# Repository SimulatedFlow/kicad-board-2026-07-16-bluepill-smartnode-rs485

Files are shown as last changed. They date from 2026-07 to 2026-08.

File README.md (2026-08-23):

# 2026-07-16-bluepill-smartnode-rs485

<!-- SF-STORE-BLOCK:BEGIN -->
## 🛒 Source-available — see before you buy

This repository contains the **full design files** of a commercial hardware board. It is **source-available, not open source**: read it, evaluate it, then buy a license to use it. See **LICENSE.md (source-available, purchase required)**.

**Get it / Buy:**
- **Order on eBay** (this board, bare PCB): https://www.ebay.de/itm/398222427962
- Product page (specs, photos, price): https://simulatedflow.teufel-engineering.com/platinen/2026-07-16-bluepill-smartnode-rs485/
- eBay store — all our boards and PCB art: https://www.ebay.de/usr/simula-9
- Merch shop (dev & gaming): https://simulatedflow.myspreadshop.de
- Merch shop (Synthetica / EDM): https://synthetica.myspreadshop.de
- Direct / invoice (Simulated Flow UG): simulatedflow@gmail.com

### 📬 **Free Board Documentation & Firmware Pack**

Schematics, BOMs and example-firmware docs for our STM32 carrier boards. Get it by joining the newsletter — plus a heads-up when something new ships. Double opt-in, unsubscribe in one click, no address sharing.

👉 **[Get the free pack](https://simulatedflow.teufel-engineering.com/newsletter/hardware/?q=gh)**

_© 2026 Simulated Flow UG. All rights reserved._
<!-- SF-STORE-BLOCK:END -->

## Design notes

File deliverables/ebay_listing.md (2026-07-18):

# BluePill-SmartNode-RS485 - Leerplatine fuer STM32 Bluepill (handloetbar, THT-Bausatz-Basis)

Handlötbares Träger- und Automationsboard für die STM32 Bluepill mit RS485-Bus, 2 robusten Relais-Ausgängen und Sensor-Schnittstellen.

## Highlights
- Komplett von Hand loetbar (THT / grosse Bauteile, kein SMD-Feinpitch)
- Passt direkt auf die STM32 'Bluepill' (2x 20-Pin-Buchsenleiste, 22,86 mm Reihenabstand)
- Schraubklemmen am Platinenrand - Kabel sauber nach aussen
- 4x M3-Befestigungsbohrungen fuer gaengige Gehaeuse
- 4-lagig (durchgehende GND- + Versorgungs-Plane, stoerarm/EMV-freundlich)

**Passendes Gehaeuse:** 100x80mm Eurocard-Gehäuse / DIN-Hutschienengehäuse (z. B. CamdenBoss CNMB/4)

## Einsatzzweck
Bastler verdrahten Bluepills für Haus- und Gartensteuerung meist fliegend über instabile Jumper-Kabel mit externen Modulen. Dieses Board vereint alle Kernfunktionen (Schalten, Bus, Sensorik, Stromversorgung) auf einer rein handlötbaren, störsicheren THT-Platine in Eurocard-Größe.

## Bestueckung (ca. 28 Bauteile laut Stueckliste)
- C_BULK1: 100uF/25V (x1)
- C_BULK2: 47uF/10V (x1)
- C_BULK3: 47uF/10V (x1)
- C_DEC1: 100nF (x1)
- C_DEC2: 100nF (x1)
- C_DEC3: 100nF (x1)
- C_DEC4: 100nF (x1)
- D_REVERSE: 1N4007 (x1)
- J_DS18B20: 1-Wire (x1)
- J_I2C: I2C OLED (x1)
- J_POWER: PWR_IN 9-24V (x1)
- J_REL1: K1 COM/NO/NC (x1)
- J_REL2: K2 COM/NO/NC (x1)
- J_RS485: RS485 A/B/GND (x1)
- K1: SRD-05VDC (x1)
- K2: SRD-05VDC (x1)
- LED1: RED (x1)
- LED2: GRN (x1)
- R1: 330R (x1)
- R2: 330R (x1)
- R_PULL1: 4.7k (x1)
- R_TERM: 120R (x1)
- U1: Bluepill_L (x1)
- U2: Bluepill_R (x1)

## Lieferumfang
- 1x unbestueckte Leiterplatte (Fertigung auf Bestellung via PCBWay)
- Schaltplan als PDF + Bestueckungsliste (BOM als CSV) zum Download

**Preis:** 24 EUR (unbestueckte Leerplatine, zzgl. Versand)

Fertigung auf Bestellung - Lieferzeit nach PCBWay-Produktion. Gewerblicher Verkauf durch Simulated Flow UG: gesetzliches Widerrufsrecht und Gewaehrleistung gemaess AGB/Impressum. Versand als versicherter Warenversand.

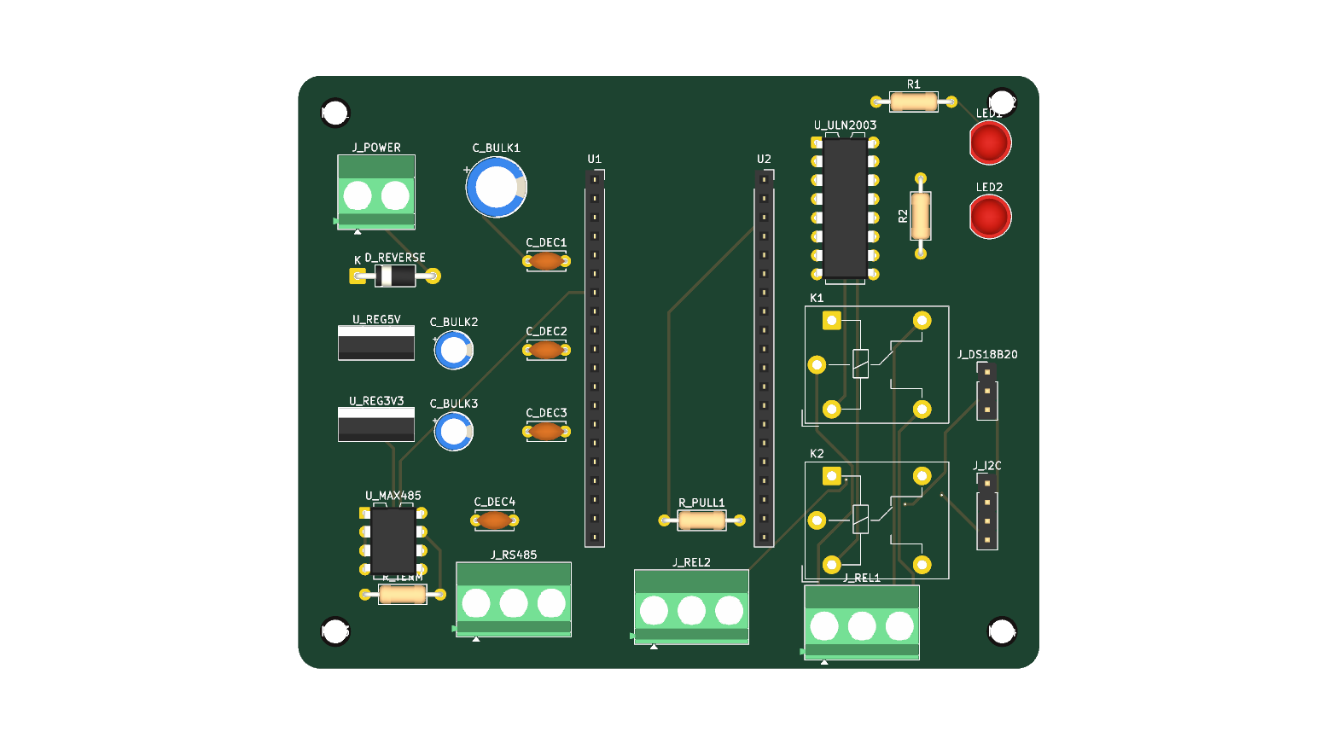
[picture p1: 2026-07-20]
deliverables/render_top.png

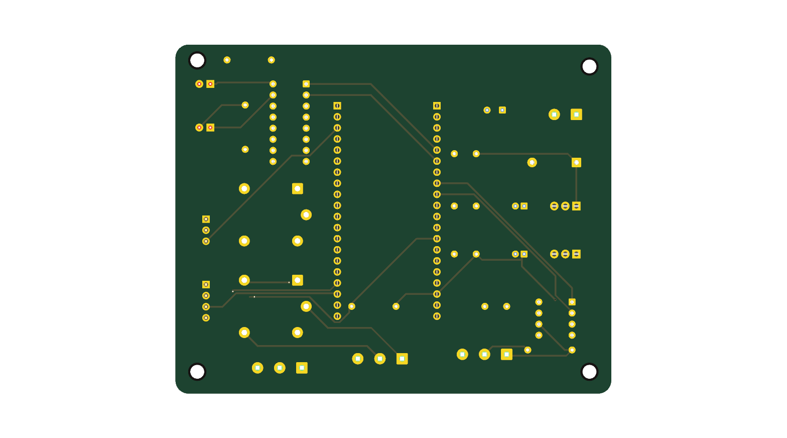
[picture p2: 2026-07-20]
deliverables/render_bottom.png

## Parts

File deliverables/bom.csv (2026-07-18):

Refs | Value | Footprint | Qty | DNP
C_BULK1 | 100uF/25V | Capacitor_THT:CP_Radial_D8.0mm_P3.50mm | 1
C_BULK2 | 47uF/10V | Capacitor_THT:CP_Radial_D5.0mm_P2.00mm | 1
C_BULK3 | 47uF/10V | Capacitor_THT:CP_Radial_D5.0mm_P2.00mm | 1
C_DEC1 | 100nF | Capacitor_THT:C_Disc_D5.0mm_W2.5mm_P5.00mm | 1
C_DEC2 | 100nF | Capacitor_THT:C_Disc_D5.0mm_W2.5mm_P5.00mm | 1
C_DEC3 | 100nF | Capacitor_THT:C_Disc_D5.0mm_W2.5mm_P5.00mm | 1
C_DEC4 | 100nF | Capacitor_THT:C_Disc_D5.0mm_W2.5mm_P5.00mm | 1
D_REVERSE? | 1N4007 | Diode_THT:D_DO-41_SOD81_P10.16mm_Horizontal | 1
J_DS18B20 | 1-Wire | Connector_PinHeader_2.54mm:PinHeader_1x03_P2.54mm_Vertical | 1
J_I2C? | I2C OLED | Connector_PinHeader_2.54mm:PinHeader_1x04_P2.54mm_Vertical | 1
J_POWER? | PWR_IN 9-24V | TerminalBlock_Phoenix:TerminalBlock_Phoenix_MKDS-1,5-2-5.08_1x02_P5.08mm_Horizontal | 1
J_REL1 | K1 COM/NO/NC | TerminalBlock_Phoenix:TerminalBlock_Phoenix_MKDS-1,5-3-5.08_1x03_P5.08mm_Horizontal | 1
J_REL2 | K2 COM/NO/NC | TerminalBlock_Phoenix:TerminalBlock_Phoenix_MKDS-1,5-3-5.08_1x03_P5.08mm_Horizontal | 1
J_RS485 | RS485 A/B/GND | TerminalBlock_Phoenix:TerminalBlock_Phoenix_MKDS-1,5-3-5.08_1x03_P5.08mm_Horizontal | 1
K1 | SRD-05VDC | Relay_THT:Relay_SPDT_Hongfa_JQC-3FF_0XX-1Z | 1
K2 | SRD-05VDC | Relay_THT:Relay_SPDT_Hongfa_JQC-3FF_0XX-1Z | 1
LED1 | RED | LED_THT:LED_D5.0mm | 1
LED2 | GRN | LED_THT:LED_D5.0mm | 1
R1 | 330R | Resistor_THT:R_Axial_DIN0207_L6.3mm_D2.5mm_P10.16mm_Horizontal | 1
R2 | 330R | Resistor_THT:R_Axial_DIN0207_L6.3mm_D2.5mm_P10.16mm_Horizontal | 1
R_PULL1 | 4.7k | Resistor_THT:R_Axial_DIN0207_L6.3mm_D2.5mm_P10.16mm_Horizontal | 1
R_TERM? | 120R | Resistor_THT:R_Axial_DIN0207_L6.3mm_D2.5mm_P10.16mm_Horizontal | 1
U1 | Bluepill_L | Connector_PinSocket_2.54mm:PinSocket_1x20_P2.54mm_Vertical | 1
U2 | Bluepill_R | Connector_PinSocket_2.54mm:PinSocket_1x20_P2.54mm_Vertical | 1
U_MAX485 | MAX485 | Package_DIP:DIP-8_W7.62mm | 1
U_REG3V3 | LD1117V33 | Package_TO_SOT_THT:TO-220-3_Vertical | 1
U_REG5V? | L7805CV | Package_TO_SOT_THT:TO-220-3_Vertical | 1
U_ULN2003 | ULN2003A | Package_DIP:DIP-16_W7.62mm | 1

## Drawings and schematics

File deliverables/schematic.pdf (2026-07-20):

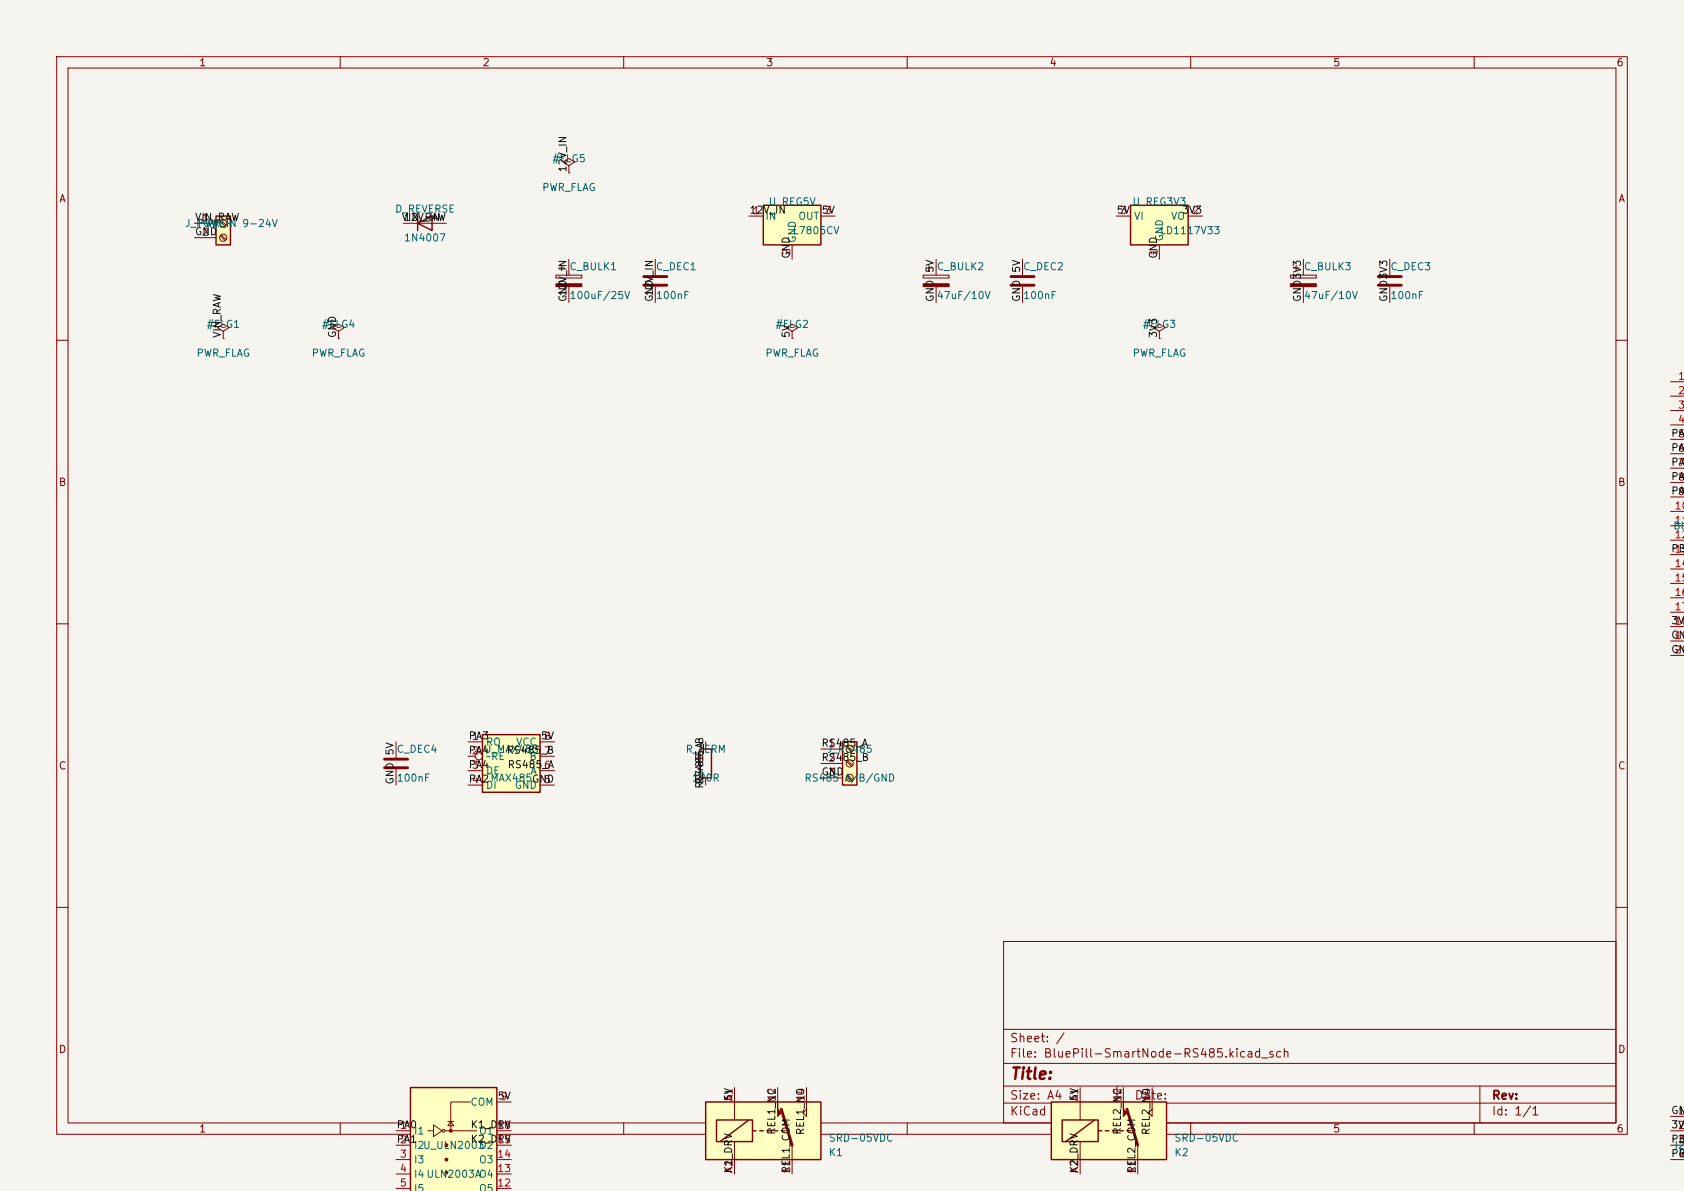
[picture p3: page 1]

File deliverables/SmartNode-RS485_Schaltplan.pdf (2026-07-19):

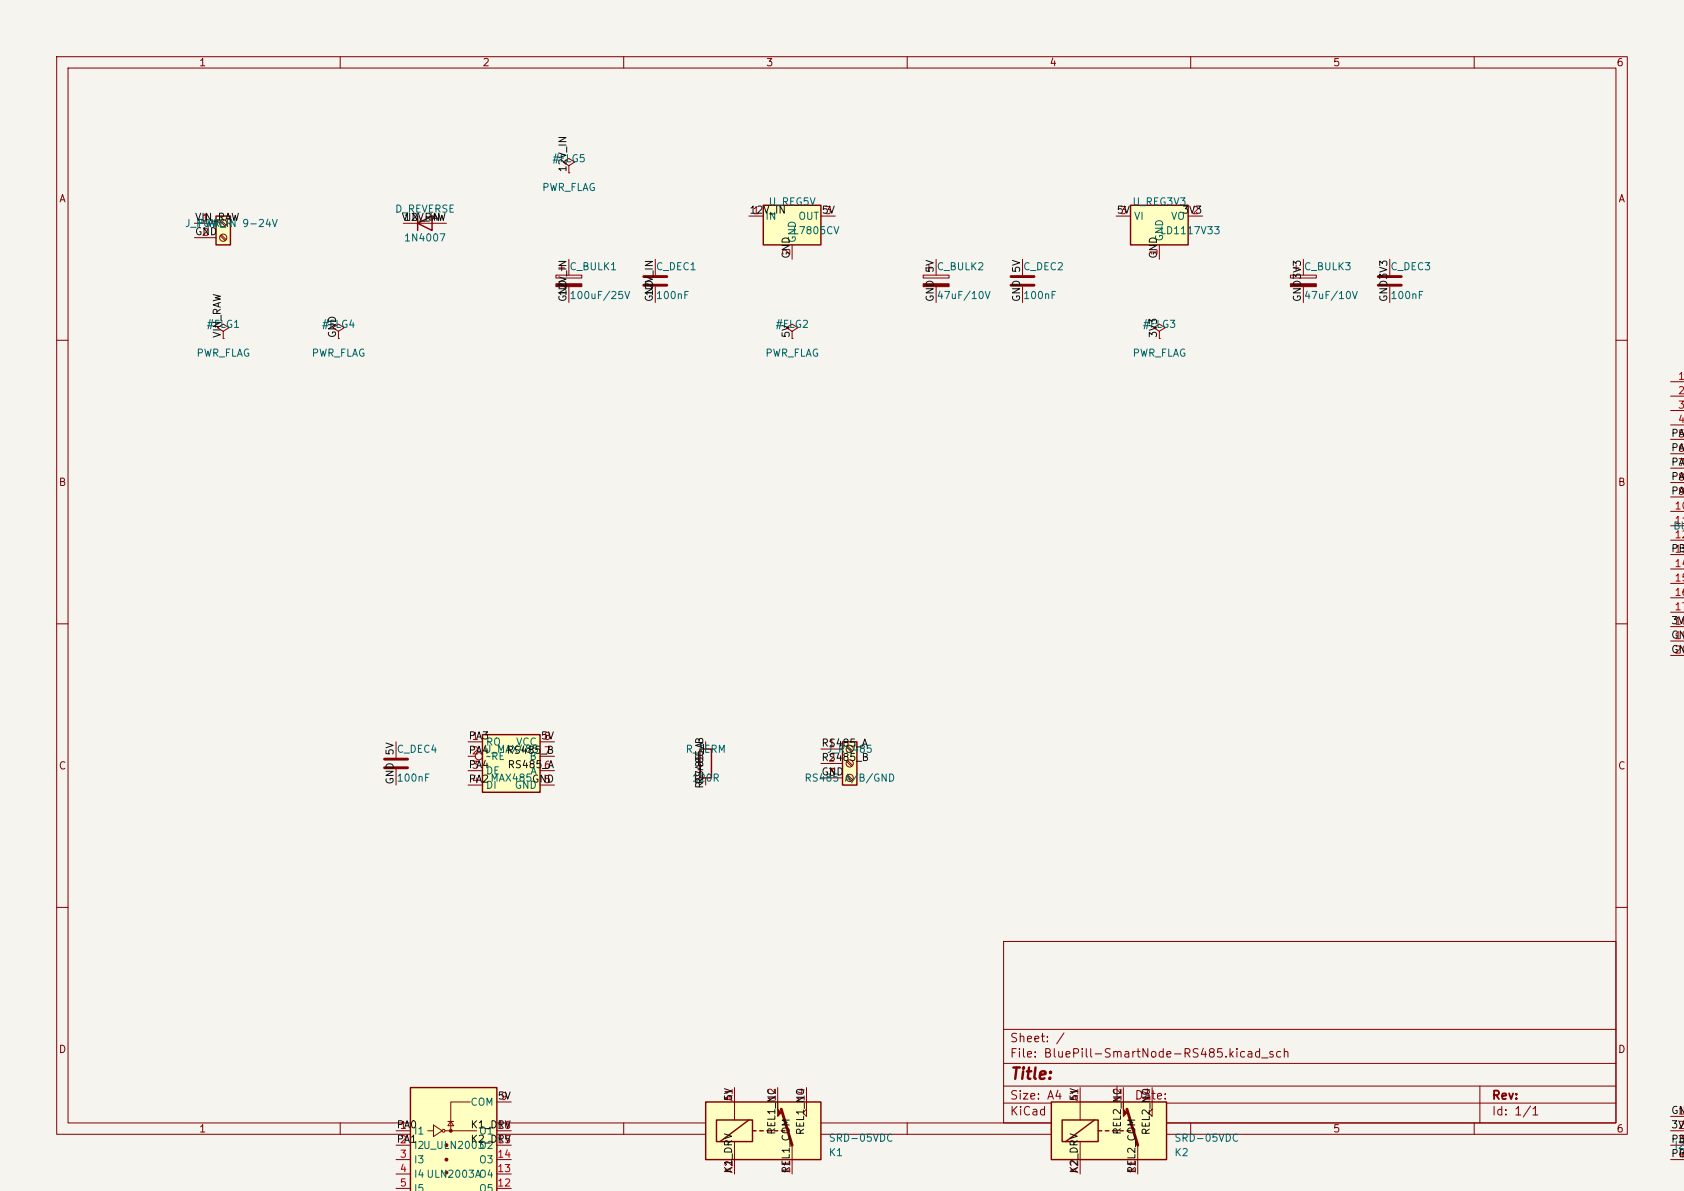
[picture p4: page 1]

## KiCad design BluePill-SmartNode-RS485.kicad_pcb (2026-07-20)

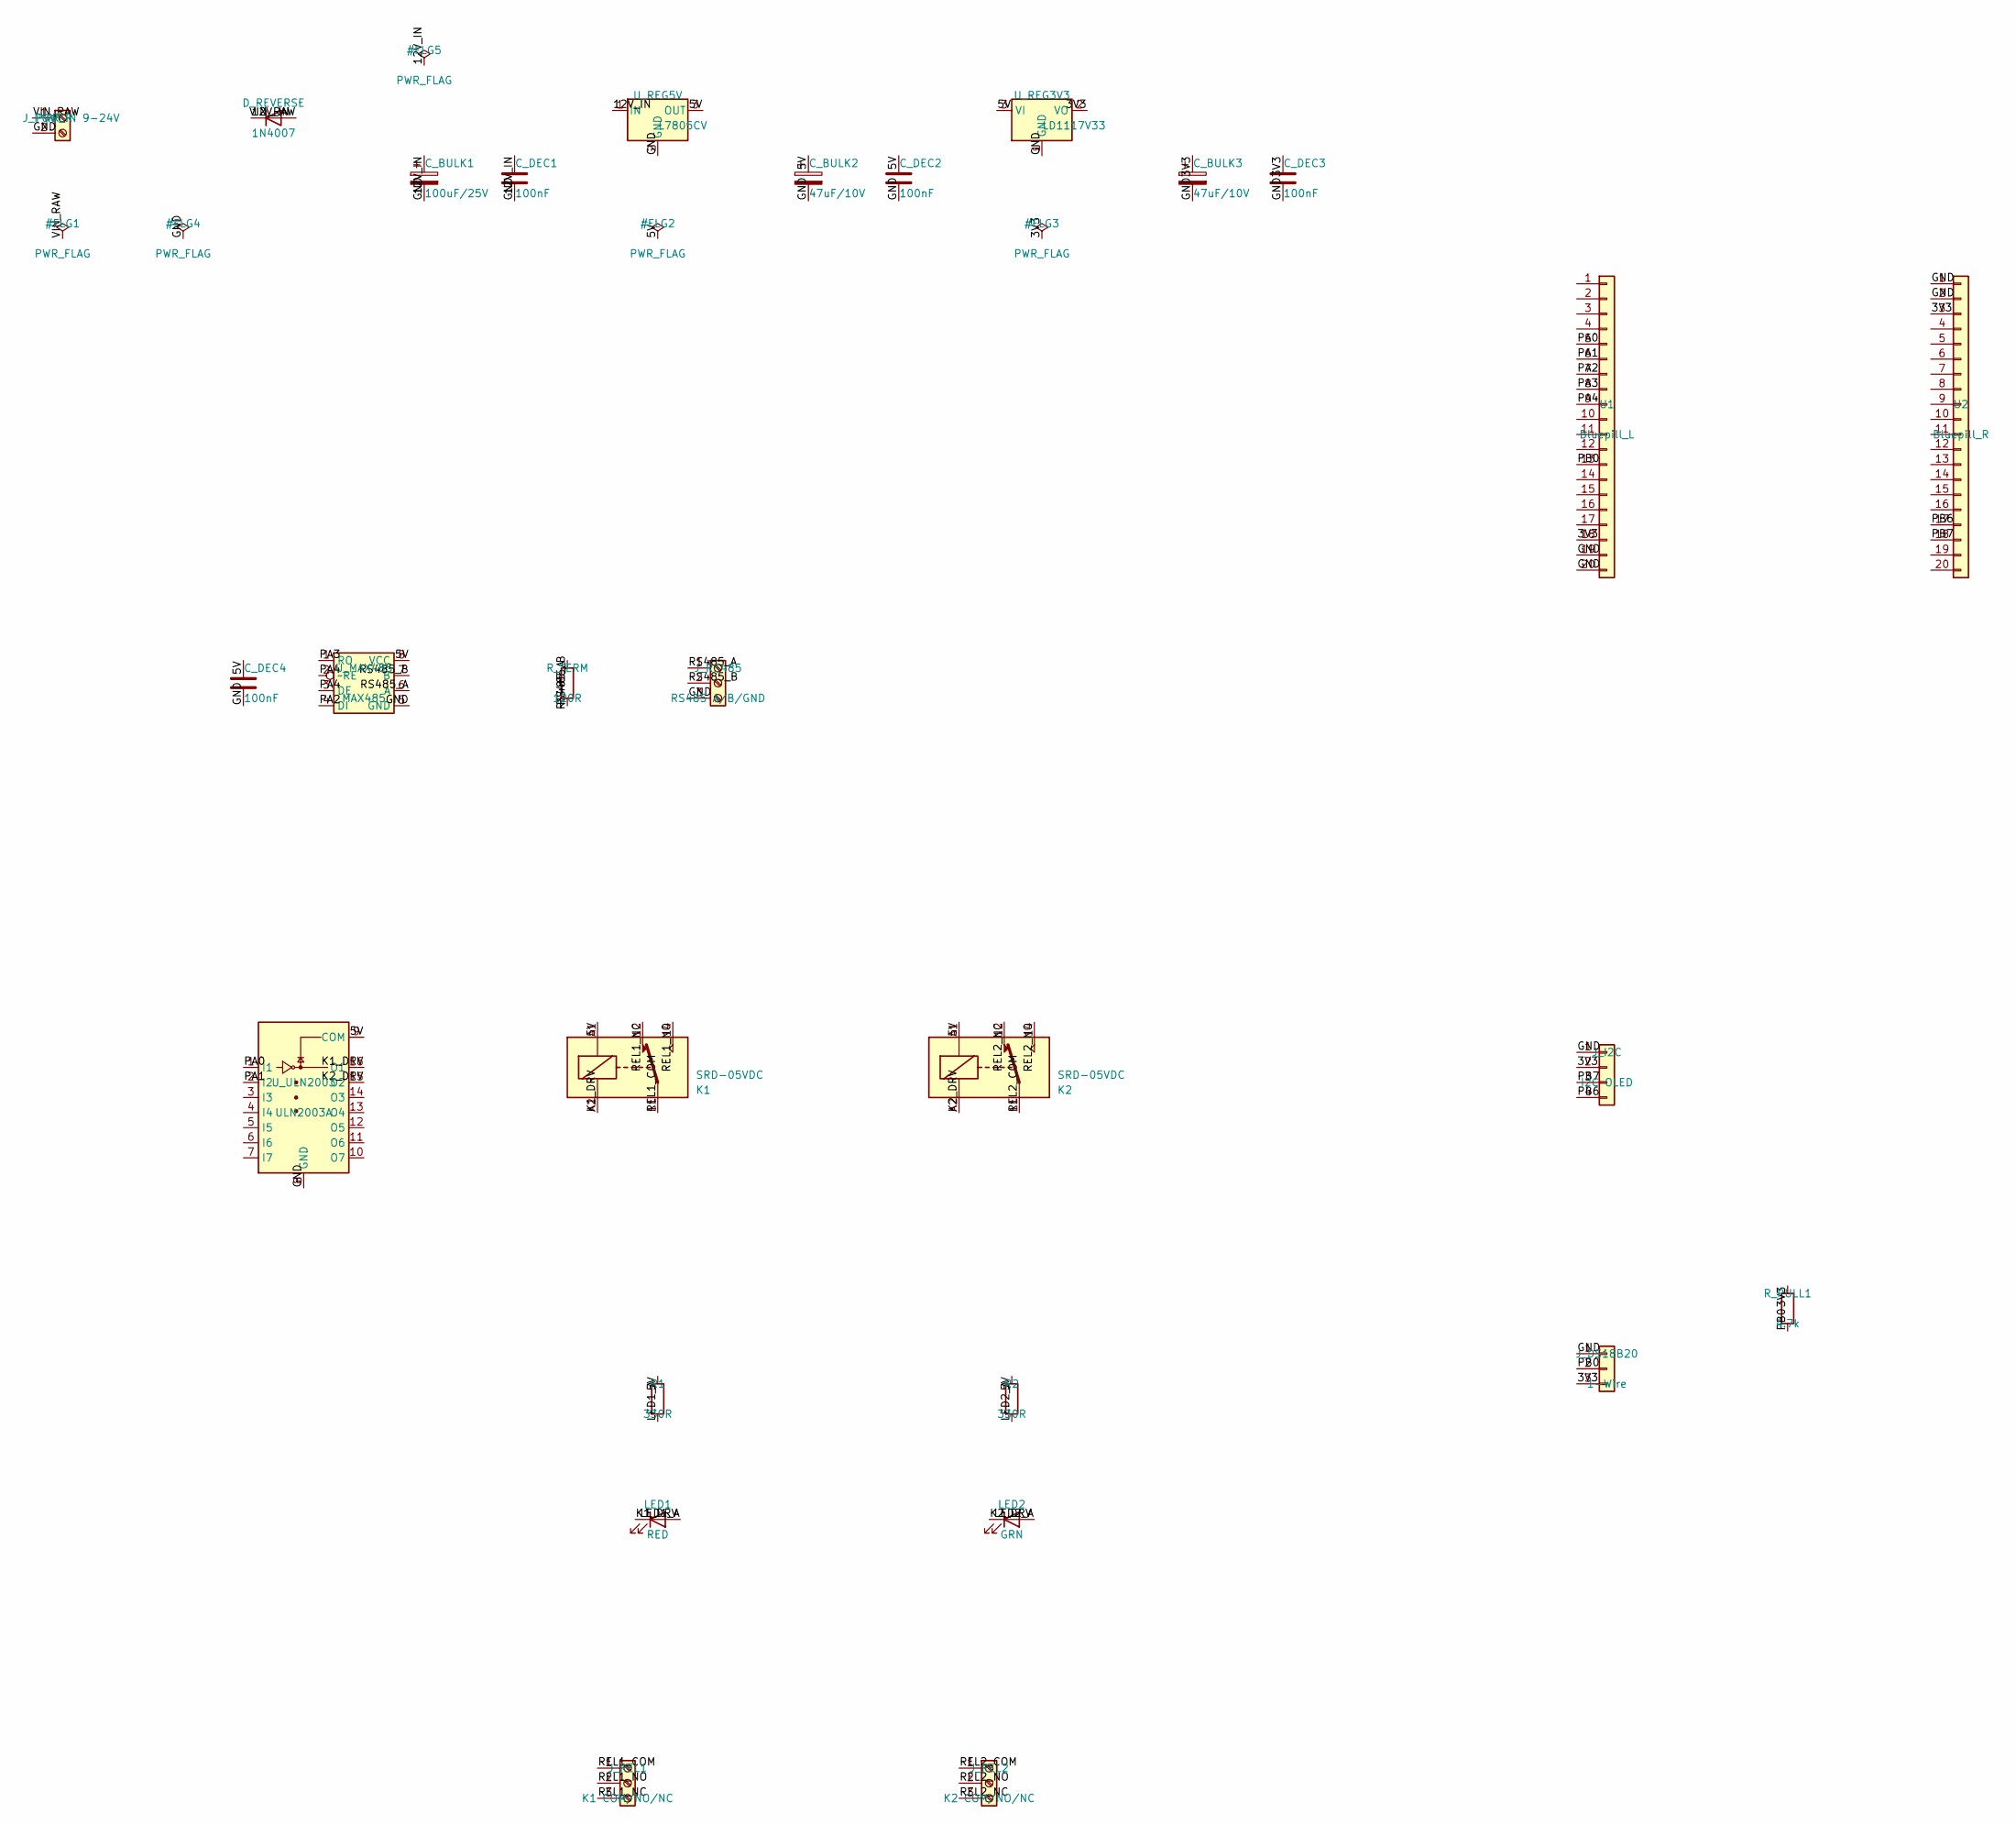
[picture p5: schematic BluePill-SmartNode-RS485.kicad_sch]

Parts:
C_BULK1: 100uF/25V; CP_Radial_D8.0mm_P3.50mm
C_BULK2, C_BULK3: 47uF/10V; CP_Radial_D5.0mm_P2.00mm
C_DEC1, C_DEC2, C_DEC3, C_DEC4: 100nF; C_Disc_D5.0mm_W2.5mm_P5.00mm
D_REVERSE: 1N4007; D_DO-41_SOD81_P10.16mm_Horizontal
J_DS18B20: 1-Wire; PinHeader_1x03_P2.54mm_Vertical
J_I2C: I2C OLED; PinHeader_1x04_P2.54mm_Vertical
J_POWER: PWR_IN 9-24V; TerminalBlock_Phoenix_MKDS-1,5-2-5.08_1x02_P5.08mm_Horizont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
J_REL1: K1 COM/NO/NC; TerminalBlock_Phoenix_MKDS-1,5-3-5.08_1x03_P5.08mm_Horizont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
J_REL2: K2 COM/NO/NC; TerminalBlock_Phoenix_MKDS-1,5-3-5.08_1x03_P5.08mm_Horizont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
J_RS485: RS485 A/B/GND; TerminalBlock_Phoenix_MKDS-1,5-3-5.08_1x03_P5.08mm_Horizont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
K1, K2: SRD-05VDC; Relay_SPDT_Hongfa_JQC-3FF_0XX-1Z
LED1: RED; LED_D5.0mm
LED2: GRN; LED_D5.0mm
R1, R2: 330R; R_Axial_DIN0207_L6.3mm_D2.5mm_P10.16mm_Horizontal
R_PULL1: 4.7k; R_Axial_DIN0207_L6.3mm_D2.5mm_P10.16mm_Horizontal
R_TERM: 120R; R_Axial_DIN0207_L6.3mm_D2.5mm_P10.16mm_Horizontal
U1: Bluepill_L; PinSocket_1x20_P2.54mm_Vertical
U2: Bluepill_R; PinSocket_1x20_P2.54mm_Vertical
U_MAX485: MAX485; DIP-8_W7.62mm
U_REG3V3: LD1117V33; TO-220-3_Vertical
U_REG5V: L7805CV; TO-220-3_Vertical
U_ULN2003: ULN2003A; DIP-16_W7.62mm

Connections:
3V3: C_BULK3.1, C_DEC3.1, J_DS18B20.3, J_I2C.2, R_PULL1.1, U1.18, U2.3, U_REG3V3.2 (VO)
5V: C_BULK2.1, C_DEC2.1, C_DEC4.1, K1.A1, K2.A1, R1.1, R2.1, U_MAX485.8 (VCC), U_REG3V3.3 (VI), U_REG5V.3 (OUT), U_ULN2003.9 (COM)
12V_IN: C_BULK1.1, C_DEC1.1, D_REVERSE.1 (K), U_REG5V.1 (IN)
GND: C_BULK1.2, C_BULK2.2, C_BULK3.2, C_DEC1.2, C_DEC2.2, C_DEC3.2, C_DEC4.2, J_DS18B20.1, J_I2C.1, J_POWER.2, J_RS485.3, U1.19, U1.20, U2.1, U2.2, U_MAX485.5 (GND), U_REG3V3.1 (GND), U_REG5V.2 (GND), U_ULN2003.8 (GND)
K1_DRV: K1.A2, LED1.1 (K), U_ULN2003.16 (O1)
K2_DRV: K2.A2, LED2.1 (K), U_ULN2003.15 (O2)
LED1_A: LED1.2 (A), R1.2
LED2_A: LED2.2 (A), R2.2
PA0: U1.5, U_ULN2003.1 (I1)
PA1: U1.6, U_ULN2003.2 (I2)
PA2: U1.7, U_MAX485.4 (DI)
PA3: U1.8, U_MAX485.1 (RO)
PA4: U1.9, U_MAX485.2 (~RE), U_MAX485.3 (DE)
PB0: J_DS18B20.2, R_PULL1.2, U1.13
PB6: J_I2C.4, U2.17
PB7: J_I2C.3, U2.18
REL1_COM: J_REL1.1, K1.11
REL1_NC: J_REL1.3, K1.12
REL1_NO: J_REL1.2, K1.14
REL2_COM: J_REL2.1, K2.11
REL2_NC: J_REL2.3, K2.12
REL2_NO: J_REL2.2, K2.14
RS485_A: J_RS485.1, R_TERM.1, U_MAX485.6 (A)
RS485_B: J_RS485.2, R_TERM.2, U_MAX485.7 (B)
VIN_RAW: D_REVERSE.2 (A), J_POWER.1

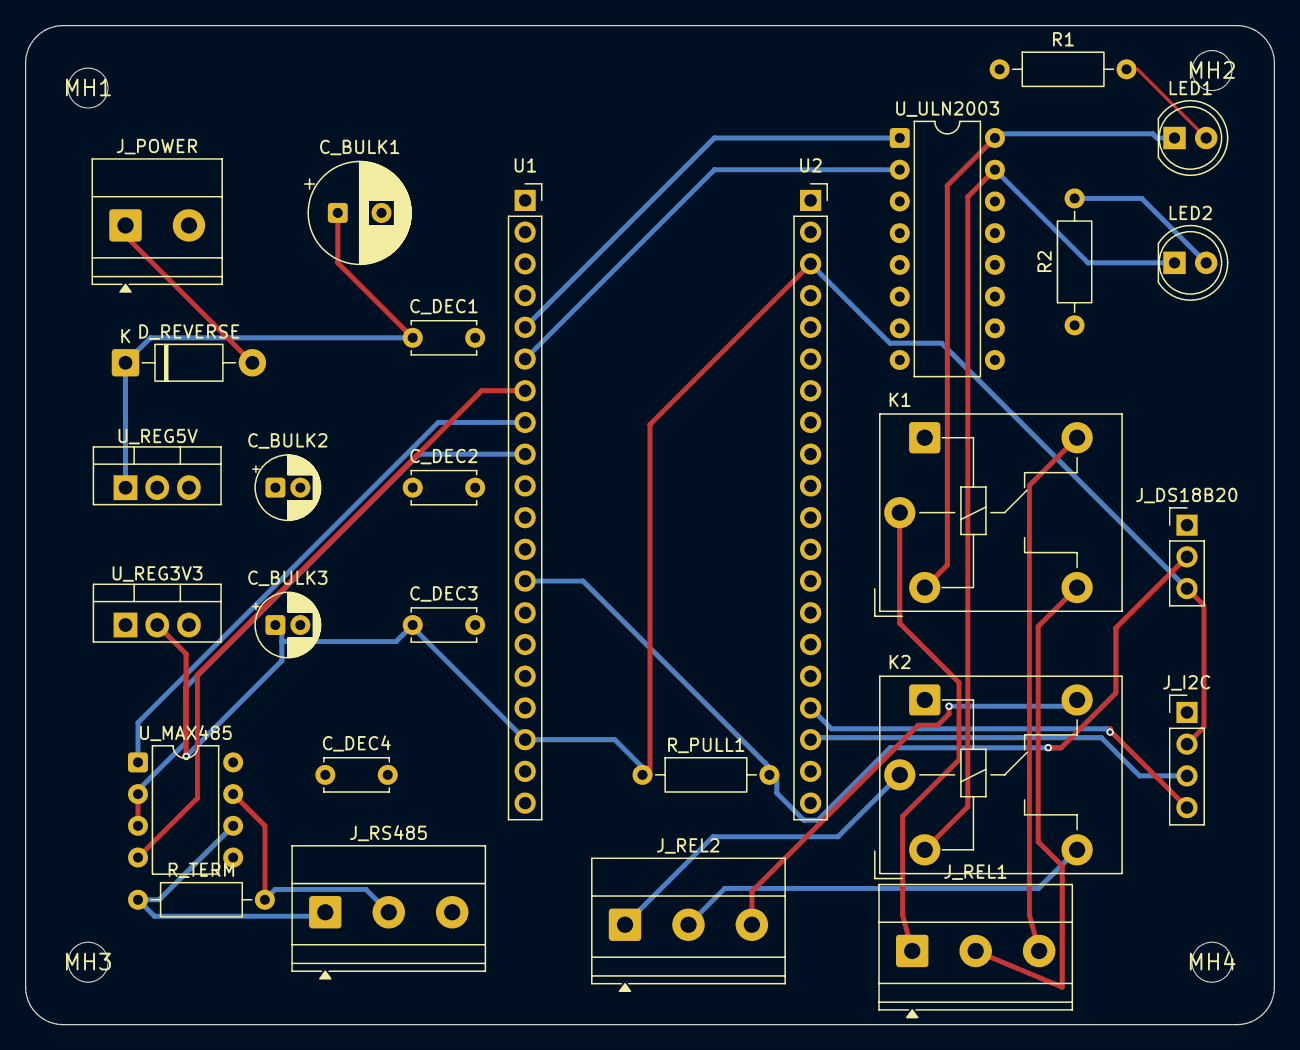
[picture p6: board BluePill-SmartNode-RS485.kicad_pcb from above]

Board: 4 copper layers, 100.0 x 80.0 mm, 32 parts (0 on the bottom side), 25 nets.

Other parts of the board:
MH1, MH2, MH3, MH4: MountingHole_3.2mm

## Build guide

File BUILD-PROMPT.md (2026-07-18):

```json
{
  "board_name": "BluePill-SmartNode-RS485",
  "one_liner": "Handlötbares Träger- und Automationsboard für die STM32 Bluepill mit RS485-Bus, 2 robusten Relais-Ausgängen und Sensor-Schnittstellen.",
  "market_gap": "Bastler verdrahten Bluepills für Haus- und Gartensteuerung meist fliegend über instabile Jumper-Kabel mit externen Modulen. Dieses Board vereint alle Kernfunktionen (Schalten, Bus, Sensorik, Stromversorgung) auf einer rein handlötbaren, störsicheren THT-Platine in Eurocard-Größe.",
  "confidence": "high",
  "price_eur": 24,
  "target_enclosure": "100x80mm Eurocard-Gehäuse / DIN-Hutschienengehäuse (z. B. CamdenBoss CNMB/4)",
  "injection_notes": "keine"
}
```

## BUILD-PROMPT

### 1. Spezifikation & Harte DFM-Vorgaben
- **Zielgruppe & Montage:** Reine Handlötbarkeit (THT-Fokus). KEINE SMD-Bauteile kleiner als 0805, bevorzugt werden DIP-Sockel, TO-220, Standard-Axialwiderstände und Standard-THT-Kondensatoren/Dioden.
- **Leiterbahnen & Abstände (Clearance):** 
  - Standard-Signal-Clearance: $\ge 0.3\,\text{mm}$
  - Standard-Signal-Leiterbahnbreite: $0.4\,\text{mm}$
  - Lastpfade (Relaiskontakte bis Schraubklemmen): $\ge 1.5\,\text{mm}$ Leiterbahnbreite (4-lagig (F.Cu/B.Cu Signal, In1.Cu GND-Plane, In2.Cu Power-Plane) verstärkt).
- **Bluepill-Sockel:** 2× 20-Pin-Buchsenleiste mit Standard-Rastermaß (RM 2.54 mm) und einem exakten Reihenabstand von **0.9″ (22.86 mm)**.
- **Anschlüsse:** Alle Schraubklemmen im RM 5.08 mm ausgeführt und direkt an den Platinenrändern platziert (Kabelauslass nach außen).
- **Massefläche:** 4-Lagen-Design (F.Cu/B.Cu Signal, In1.Cu durchgehende GND-Plane, In2.Cu durchgehende Versorgungs-Plane) mit einer durchgehenden GND-Kupferfläche auf dem Bottom-Layer (`B.Cu`).

---

### 2. Mechanik (Abmessungen & Bohrungen)
- **Board-Größe:** Exakt $100.0\,\text{mm} \times 80.0\,\text{mm}$ (Ecken abgerundet).
- **Befestigungslöcher:** 4× M3-Befestigungsbohrungen (Durchmesser $3.2\,\text{mm}$) an den exakten Koordinaten (Ursprung unten links bei (0,0)):
  - Loch 1: $(5.0\,\text{mm}, 5.0\,\text{mm})$
  - Loch 2: $(95.0\,\text{mm}, 5.0\,\text{mm})$
  - Loch 3: $(5.0\,\text{mm}, 75.0\,\text{mm})$
  - Loch 4: $(95.0\,\text{mm}, 75.0\,\text{mm})$
- **Keepout:** $5.0\,\text{mm}$ kreisförmiger Sperrbereich (Keepout) um alle vier Bohrlöcher für Schraubenköpfe/Unterlegscheiben.

---

### 3. Bestückungs- & Bauteilliste (BOM)

#### Stromversorgung (9-24V DC Input auf 5V und 3.3V):
- **J_POWER:** 2-polige Schraubklemme (RM 5.08 mm) – *Footprint: TerminalBlock_Phoenix:TerminalBlock_Phoenix_MKDS-1.5-2-5.08_1x02_P5.08mm_Horizontal*
- **D_REVERSE:** 1N4007 Verpolschutzdiode (THT DO-41) – *Footprint: Diode_THT:D_DO-41_SOD81_P10.16mm_Horizontal*
- **C_BULK1:** 100 µF / 25 V Elektrolytkondensator (THT) – *Footprint: Capacitor_THT:CP_Radial_D8.0mm_P3.50mm*
- **U_REG5V:** L7805CV linearer Spannungsregler (TO-220, stehend, liefert 5V für Relais/RS485) – *Footprint: Package_TO_SOT_THT:TO-220-3_Vertical*
- **U_REG3V3:** LD1117V33 oder LF33CV linearer Spannungsregler (TO-220, stehend, liefert stabile 3.3V für Bluepill/Sensoren) – *Footprint: Package_TO_SOT_THT:TO-220-3_Vertical*
- **C_BULK2, C_BULK3:** 2× 47 µF / 10 V Elkos (THT) – *Footprint: Capacitor_THT:CP_Radial_D5.0mm_P2.00mm*
- **C_DEC1, C_DEC2, C_DEC3:** 3× 100 nF Keramikkondensatoren (Stützkondensatoren, THT) – *Footprint: Capacitor_THT:C_Disc_D5.0mm_W2.5mm_P5.00mm*

#### Mikrocontroller & Logik:
- **U1, U2 (Bluepill-Sockel):** 2× PinSocket 1x20 (RM 2.54 mm, Reihenabstand 22.86 mm) – *Footprint: Connector_PinSocket:PinSocket_1x20_P2.54mm_Vertical*

#### RS485-Bus (MAX485):
- **U_MAX485:** MAX485 Transceiver im DIP-8-Gehäuse (gesockelt) – *Footprint: Package_DIP:DIP-8_W7.62mm*
- **C_DEC4:** 100 nF Stützkondensator für MAX485 – *Footprint: Capacitor_THT:C_Disc_D5.0mm_W2.5mm_P5.00mm*
- **R_TERM:** Optionale 120 Ohm Abschlusswiderstand (THT, zuschaltbar über Lötbrücke oder direkt bestückt) – *Footprint: Resistor_THT:R_Axial_DIN0207_L6.3mm_D2.5mm_P10.16mm_Horizontal*
- **J_RS485:** 3-polige Schraubklemme (RM 5.08 mm, Anschlüsse: A, B, GND) – *Footprint: TerminalBlock_Phoenix:TerminalBlock_Phoenix_MKDS-1.5-3-5.08_1x03_P5.08mm_Horizontal*

#### Relais-Ausgänge (2-Kanal):
- **U_ULN2003:** ULN2003A Darlington-Transistor-Array im DIP-16-Gehäuse (gesockelt; nur 2 der 7 Kanäle genutzt, integrierte Freilaufdioden/Basiswiderstände vereinfachen das Layout) – *Footprint: Package_DIP:DIP-16_W7.62mm*
- **K1, K2:** 2× Printrelais 5VDC (Typ Songle SRD-05VDC-SL-C) – *Footprint: Relay_THT:Relay_SPDT_Sanyou_SRD_Series_Form_C*
- **LED1, LED2:** 2× LED 5 mm (Statusanzeige rot/grün) – *Footprint: LED_THT:LED_D5.0mm*
- **R1, R2:** 2× 330 Ohm Vorwiderstände für LEDs – *Footprint: Resistor_THT:R_Axial_DIN0207_L6.3mm_D2.5mm_P10.16mm_Horizontal*
- **J_REL1, J_REL2:** 2× 3-polige Schraubklemmen (RM 5.08 mm, Belegung: COM, NO, NC) – *Footprint: TerminalBlock_Phoenix:TerminalBlock_Phoenix_MKDS-1.5-3-5.08_1x03_P5.08mm_Horizontal*

#### Sensor-Schnittstellen:
- **J_I2C:** 4-Pin Stiftleiste für OLED-Display (GND, 3.3V, SDA, SCL) – *Footprint: Connector_PinHeader_2.54mm:PinHeader_1x04_P2.54mm_Vertical*
- **J_DS18B20:** 3-Pin Stiftleiste für Dallas One-Wire Sensoren (GND, DQ, 3.3V) – *Footprint: Connector_PinHeader_2.54mm:PinHeader_1x03_P2.54mm_Vertical*
- **R_PULL1:** 4.7k Ohm Pull-up-Widerstand (THT) für DS18B20 – *Footprint: Resistor_THT:R_Axial_DIN0207_L6.3mm_D2.5mm_P10.16mm_Horizontal*

---

### 4. Verdrahtungsplan (Netz-Labels)

#### Strom & Masse:
- `GND`: Zentraler Massebus. Verbindet J_POWER Pin 2, alle Elko-/Kerko-GNDs, Regler-GNDs, Bluepill GND, ULN2003 Pin 8, MAX485 Pin 5, Sensor-GNDs und J_RS485 Pin 3.
- `12V_IN`: Ausgang von D_REVERSE, führt zu C_BULK1, C_DEC1 und U_REG5V Input.
- `5V`: Ausgang von U_REG5V, führt zu C_BULK2, C_DEC2, U_REG3V3 Input, MAX485 Pin 8, ULN2003 Pin 9 (COM) und den Spulen der Relais K1-K2. Führt auch an den 5V-Pin der Bluepill (Einspeisung).
- `3.3V`: Ausgang von U_REG3V3, führt zu C_BULK3, C_DEC3, dem Pull-up-Widerstand R_PULL1 und den Sensor-Headern J_I2C, J_DS18B20.

#### Mikrocontroller-Steuerleitungen:
- **Relais-Kanäle (2):**
  - `PA0` $\rightarrow$ U_ULN2003 Pin 1 (IN1) $\rightarrow$ Pin 16 (OUT1) $\rightarrow$ Spule K1 (und LED1 mit R1)
  - `PA1` $\rightarrow$ U_ULN2003 Pin 2 (IN2) $\rightarrow$ Pin 15 (OUT2) $\rightarrow$ Spule K2 (und LED2 mit R2)
- **RS485-Interface:**
  - `PA2` (USART2_TX) $\rightarrow$ U_MAX485 Pin 4 (DI)
  - `PA3` (USART2_RX) $\rightarrow$ U_MAX485 Pin 1 (RO)
  - `PA4` (TX_EN) $\rightarrow$ Verbunden mit U_MAX485 Pin 2 (~RE) und Pin 3 (DE) zur Richtungssteuerung.
- **I2C-Sensor-Bus:**
  - `PB6` (I2C1_SCL) $\rightarrow$ J_I2C Pin 4 (SCL)
  - `PB7` (I2C1_SDA) $\rightarrow$ J_I2C Pin 3 (SDA)
- **Sensor-Eingänge:**
  - `PB0` $\rightarrow$ J_DS18B20 Pin 2 (DQ)

---

### 5. Arbeitsanweisung für den Bau-Agenten
1. **Projekt-Setup:** Erstelle ein neues KiCad-Projekt mit dem Namen `BluePill-SmartNode-RS485`.
2. **Schaltplan erstellen:** Platziere alle oben genannten Symbole. Weise jedem Symbol den exakt spezifizierten Footprint zu. Verbinde alle Netze sauber mit globalen Labels.
3. **Leiterplatten-Layout (PCB):**
   - Zeichne den Board-Umriss (`Edge.Cuts`) auf ein exaktes Rechteck von $100.0\,\text{mm} \times 80.0\,\text{mm}$.
   - Setze die 4× M3-Befestigungslöcher auf die definierten Positionen und sperre die Keepout-Zonen.
   - Platziere den Bluepill-Sockel mittig.
   - Ordne alle Schraubklemmen (J_POWER, J_RS485, J_REL1 - J_REL4) entlang der Ränder an, so dass die Kabeleinführung nach außen zeigt.
   - Platziere die Entkopplungskondensatoren so nah wie möglich an den jeweiligen IC-Power-Pins (insb. MAX485 und Regler).
   - Platziere die Status-LEDs gut sichtbar neben den jeweiligen Relais.
4. **Routing (4 Lagen, dedizierte Planes):**
   - Setze das Board auf 4 Kupferlagen: F.Cu (Signal) / In1.Cu (durchgehende GND-Plane) / In2.Cu (durchgehende Versorgungs-Plane, Netz `5V`) / B.Cu (Signal). Lege GND-Zone auf In1.Cu und 5V-Zone auf In2.Cu über die ganze Fläche an.
   - Route Signalleitungen AUSSCHLIESSLICH auf F.Cu und B.Cu; GND und 5V kommen über die Planes + Vias (dadurch viel weniger Routing-Dichte). Keine Signale auf In1/In2.
   - Nutze für Relais-Lastpfade eine Leiterbahnbreite von mindestens $1.5\,\text{mm}$.
5. **Prüfung (DRC):** Führe den Design Rule Check (DRC) durch. Korrigiere alle Clearance- und Überlappungsfehler.
6. **Export:** Exportiere die Gerber- und Excellon-Bohrdaten strukturiert in das Verzeichnis `./gerbers`.

*Zusammenfassung:* Bitte führe das Design autonom durch und erstelle am Ende einen ehrlichen Bericht, welche Schritte erfolgreich abgeschlossen wurden.

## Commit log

2026-07-18 auto-backup 2026-07-18 16:25:51
    [BluePill-SmartNode-RS485-B_Courtyard.gbr, BluePill-SmartNode-RS485-B_Cu.gbl, BluePill-SmartNode-RS485-B_Fab.gbr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]
2026-07-18 auto-backup 2026-07-18 16:57:53
    [BluePill-SmartNode-RS485-B_Courtyard.gbr, BluePill-SmartNode-RS485-B_Cu.gbl, BluePill-SmartNode-RS485-B_Fab.gbr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]
2026-07-19 auto-backup 2026-07-19 21:26:17
    [BluePill-SmartNode-RS485.kicad_pcb]
2026-07-20 auto-backup 2026-07-20 13:26:17
    [BluePill-SmartNode-RS485.kicad_pcb]
2026-07-20 auto-backup 2026-07-20 15:26:19
    [BluePill-SmartNode-RS485-B_Courtyard.gbr, BluePill-SmartNode-RS485-B_Cu.gbl, BluePill-SmartNode-RS485-B_Fab.gbr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]
